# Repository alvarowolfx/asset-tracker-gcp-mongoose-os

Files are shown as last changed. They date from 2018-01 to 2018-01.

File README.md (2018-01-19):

# Asset Tracker using MongooseOS and Google Cloud

## Overview

IoT Project using MongooseOS with it's awesome GPRS with PPPoS. Data will be sent to Google Cloud to be analysed and visualized.

WebApp: https://asset-tracker-iot.firebaseapp.com

### Upload firmware with Mongoose OS Tools

To use it we need to download and install it from the official website. Follow the installation instructions on https://mongoose-os.com/docs/quickstart/setup.html.

* `mos build --arch esp32`
* `mos flash`

### Provision and config

* `mos wifi your_ssid your_pass`
* `mos gcp-iot-setup --gcp-project your_project --gcp-region us-central1 --gcp-registry your_registry`

### BOM

* Any ESP32 Board (I used a Lolin32).
* NEO 6M uBlox GPS module.
* Sim800L GSM module.
* 220 Ohm resistor for the LED.
* Blue and Green LED for status of the device.
* 1k Ohm resistor for the MOSFET trigger.
* IRF540N MOSFET (don’t try to use a cheap MOSFET, like the TIP120, because it cannot handle the GSM Module current needs)
* Jumpers
* Perfboard for prototype (Optional)

### Schematic

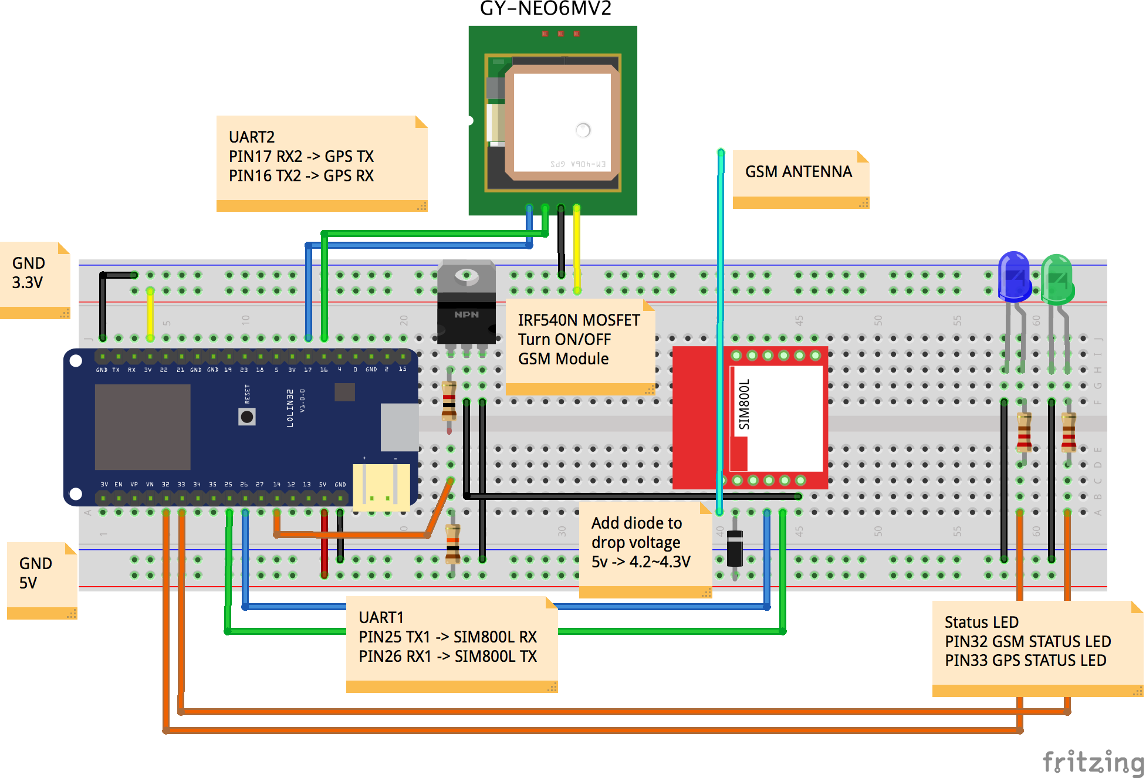
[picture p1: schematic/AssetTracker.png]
schematic


### Setup Firebase, deploy functions and webapp

* Install firebase tools: `npm install -g firebase-tools` or `yarn global add firebase-tools`
* Install webapp dependencies: `npm install` or `yarn install`
* Build React Application: `yarn run build` or `yarn run build`
* Install functions dependencies: `cd functions && npm install` or `cd functions && yarn install`
* Associate project with Firebase: `firebase init`
* Deploy all the things: `firebase deploy`

## References

* https://github.com/mongoose-os-apps/example-rpc-c
* https://github.com/mongoose-os-libs/pppos
* GPS NMEA Tracker - https://github.com/kosma/minmea

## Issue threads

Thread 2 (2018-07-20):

Watchdog  got triggered

vishnu-chalil, 2018-07-20:
I really dont understand what is the problem but when I run after falshing the code I get this error
Somebody please Help

[Jul 20 13:22:28.841] Task watchdog got triggered. The following tasks did not reset the watchdog in time:
[Jul 20 13:22:28.849]  - IDLE (CPU 0), backtrace: 0x400d13f4 0x40085f77
[Jul 20 13:22:28.854]
[Jul 20 13:22:28.854] Tasks currently running:
[Jul 20 13:22:28.856] CPU 0: mgos
[Jul 20 13:22:28.857] Aborting.
[Jul 20 13:22:28.858] abort() was called at PC 0x400d0f54 on core 0
[Jul 20 13:22:28.862]
[Jul 20 13:22:28.862] Backtrace: 0x4008775f 0x4008785f 0x400d0f54 0x40081cba 0x40129d73
[Jul 20 13:22:28.868] --- BEGIN CORE DUMP ---
[Jul 20 13:22:28.869] mos: catching core dump

vishnu-chalil, 2018-07-20:
And also can someone please tell what this means

[Jul 20 13:33:27.650] mgos_http_server_ini HTTP server started on [80]
[Jul 20 13:33:27.656] mgos_pppos_create    PPPoS UART1, 115200, fc off, APN 'www'
[Jul 20 13:33:27.664] mg_rpc_channel_uart  0x3ffd1000 UART0

alvarowolfx, 2018-07-23:
Can you show your APN config and what cellular network provider are you using ?

vishnu-chalil, 2018-08-02:
config_schema:
  - ["app", "o", {title: "App config"}]
  - ["app.update_interval", "i", 300, {title: "Update interval in seconds"}]
  - ["pppos.enable", true]
  - ["pppos.uart_no", 1]
  - ["pppos.baud_rate", 115200]
  - ["pppos.apn", "airtelgprs.com"]
  - ["pppos.user", ""]
  - ["pppos.pass", ""]
  - ["pppos.connect_cmd", "ATD*99***1#"]
  - ["gps.uart_no", 2]
  - ["gps.baud_rate", 9600]
  - ["gps.update_interval", 2000]
  - ["wifi.sta.enable", false]

Cellular network provider is airtel

vishnu-chalil, 2018-08-03:
I found the mistake.It was an error with incorrect pin connection

Closed 2018-08-03.

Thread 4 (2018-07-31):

MQTT SSL error

hexfusion, 2018-07-31:
GCP is very sensitive to time sync issues which can result in MQTT SSL errors.

ref: https://github.com/mongoose-os-libs/gcp/issues/1

vishnu-chalil, 2018-08-06:
I updated and build the firmware with new version tools and now I am stuck in this.All I get is this output

	[Aug  3 21:48:10.173] Setting timer with  300  seconds interval
	[Aug  3 21:48:10.188]   at init.js:181
	[Aug  3 21:48:10.190] MJS error: calling non-callable
	[Aug  3 21:48:10.193] mgos_pppos_uart_disp Connecting (UART2, APN 'airtelgprs.com')...
	[Aug  3 21:48:10.201] mongoose_poll        New heap free LWM: 188456
	[Aug  3 21:48:10.206] mgos_net_on_change_c PPP: disconnected
	[Aug  3 21:48:12.690] mgos_net_on_change_c PPP: connecting
	[Aug  3 21:48:12.825] mgos_net_on_change_c PPP: connected
	[Aug  3 21:48:12.829] mgos_pppos_uart_disp Starting PPP, user ''
	[Aug  3 21:48:12.848] mongoose_poll        New heap free LWM: 186520
	[Aug  3 21:48:18.880] mgos_pppos_status_cb Error 6 (phase 0), reconnect
	[Aug  3 21:48:18.886] mgos_pppos_uart_disp Connecting (UART2, APN 'airtelgprs.com')...
	```
	[Aug  3 21:48:18.893] mgos_net_on_change_c PPP: disconnected
	[Aug  3 21:48:21.281] mgos_net_on_change_c PPP: connecting
	[Aug  3 21:48:21.796] mgos_net_on_change_c PPP: connected
	[Aug  3 21:48:21.801] mgos_pppos_uart_disp Starting PPP, user ''
	[Aug  3 21:48:21.820] mongoose_poll        New heap free LWM: 185688
	[Aug  3 21:48:27.851] mgos_pppos_status_cb Error 6 (phase 0), reconnect
	[Aug  3 21:48:27.857] mgos_pppos_uart_disp Connecting (UART2, APN 'airtelgprs.com')...

Is there something that I could have possibly missed

Closed 2018-07-31.

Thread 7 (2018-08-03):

MJS error: calling non-callable

vishnu-chalil, 2018-08-03:
I updated and builded the firmware with new version tools and now Iam stuck in this.All I get is this output

[Aug  3 21:48:10.173] Setting timer with  300  seconds interval
[Aug  3 21:48:10.188]   at init.js:181
[Aug  3 21:48:10.190] MJS error: calling non-callable
[Aug  3 21:48:10.193] mgos_pppos_uart_disp Connecting (UART2, APN 'airtelgprs.com')...
[Aug  3 21:48:10.201] mongoose_poll        New heap free LWM: 188456
[Aug  3 21:48:10.206] mgos_net_on_change_c PPP: disconnected
[Aug  3 21:48:12.690] mgos_net_on_change_c PPP: connecting
[Aug  3 21:48:12.825] mgos_net_on_change_c PPP: connected
[Aug  3 21:48:12.829] mgos_pppos_uart_disp Starting PPP, user ''
[Aug  3 21:48:12.848] mongoose_poll        New heap free LWM: 186520
[Aug  3 21:48:18.880] mgos_pppos_status_cb Error 6 (phase 0), reconnect
[Aug  3 21:48:18.886] mgos_pppos_uart_disp Connecting (UART2, APN 'airtelgprs.com')...
[Aug  3 21:48:18.893] mgos_net_on_change_c PPP: disconnected
[Aug  3 21:48:21.281] mgos_net_on_change_c PPP: connecting
[Aug  3 21:48:21.796] mgos_net_on_change_c PPP: connected
[Aug  3 21:48:21.801] mgos_pppos_uart_disp Starting PPP, user ''
[Aug  3 21:48:21.820] mongoose_poll        New heap free LWM: 185688
[Aug  3 21:48:27.851] mgos_pppos_status_cb Error 6 (phase 0), reconnect
[Aug  3 21:48:27.857] mgos_pppos_uart_disp Connecting (UART2, APN 'airtelgprs.com')...

bblanke, 2020-02-19:
Howdy! You might need to add the function to your object in Object.create.

Example from my code from another project:

`let ThermalPrinter = {
  create: function(uart_no, dtr_pin, heatTime) {
    return Object.create({
      _i: ThermalPrinter._c(uart_no, dtr_pin, heatTime),

      print: ThermalPrinter.print,
      had to add this >> println: ThermalPrinter.println
    });
  },

  print: function(str) {
    ThermalPrinter._print(this._i, str, str.length);
  },

  println: function(str) {
    ThermalPrinter._println(this._i, str, str.length);
  },

  _c: ffi('void *thermal_printer_create(int, int, int)'),
  _print: ffi('void print(void *, char *, int)'),
  _println: ffi('void println(void *, char *, int)'),
}`

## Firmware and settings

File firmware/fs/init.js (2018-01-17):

load('api_config.js');
load('api_uart.js');
load('api_gpio.js');
load('api_net.js');
load('api_mqtt.js');
load('api_sys.js');
load('api_timer.js');
load('api_esp32.js');
load('api_gps.js');

let isConnected = false;
let isGPSLocked = false;
let telemetrySend = false;
let deviceName = Cfg.get('device.id');
let topic = '/devices/' + deviceName + '/events';
//let stateTopic = '/devices/' + deviceName + '/state';
let configTopic = '/devices/' + deviceName + '/config';

let gpsStatusPin = 33;
let gsmStatusPin = 32;
let gsmSwitchPin = 14;

GPIO.set_mode(gpsStatusPin, GPIO.MODE_OUTPUT);
GPIO.set_mode(gsmStatusPin, GPIO.MODE_OUTPUT);
GPIO.set_mode(gsmSwitchPin, GPIO.MODE_OUTPUT);

GPIO.write(gpsStatusPin, 0); // Turn off gps led
GPIO.write(gsmStatusPin, 0); // Turn off gsm led
GPIO.write(gsmSwitchPin, 1); // Turn on gsm module

function getTemp() {
  return (ESP32.temp() - 32) * 5 / 9;
}

function getParsedLatLon() {
  return GPS.getLocation();
}

let getInfo = function() {
  return JSON.stringify({
    total_ram: Sys.total_ram() / 1024,
    free_ram: Sys.free_ram() / 1024,
    temp: getTemp(),
    latlon: getParsedLatLon()
  });
};

function publishData() {
  let msg = getInfo();
  let ok = MQTT.pub(topic, msg);
  if (ok) {
    print('Published');
  } else {
    print('Error publishing');
  }
  return ok;
}

// Sleep function, turning off all LEDs and GSM modem.
let updateTimerId = null;
let gpsTimerId = null;
function goToSleep() {
  print('Sleeping');
  Timer.del(gpsTimerId);
  Timer.del(updateTimerId);
  Timer.set(
    8000,
    false,
    function() {
      GPIO.write(gpsStatusPin, 0); // Turn off gps led
      GPIO.write(gsmStatusPin, 0); // Turn off gsm led
      GPIO.write(gsmSwitchPin, 0); // Turn off gsm module

      let updateInterval = Cfg.get('app.update_interval');

      ESP32.deepSleep(updateInterval * 1000 * 1000);
    },
    null
  );
}

// Setup a timer that keep track of the time that the device is on but didn't send data yet.
// After some tries it goes to sleep.
let sendTelemetryTries = 0;
function setUpdateTimer() {
  if (updateTimerId) {
    Timer.del(updateTimerId);
  }
  let updateInterval = Cfg.get('app.update_interval');
  print('Setting timer with ', updateInterval, ' seconds interval');
  updateTimerId = Timer.set(
    updateInterval * 1000,
    true,
    function() {
      print('Should send telemetry');
      sendTelemetryTries = sendTelemetryTries + 1;
      if (sendTelemetryTries > 1 && !telemetrySend) {
        goToSleep();
      }
      telemetrySend = false;
    },
    null
  );
}
setUpdateTimer();

// Check if GPS has valid data.
gpsTimerId = Timer.set(
  1000,
  true,
  function() {
    let geo = getParsedLatLon();
    if (geo) {
      isGPSLocked = true;
      GPIO.write(gpsStatusPin, 1);
    } else {
      isGPSLocked = false;
      GPIO.write(gpsStatusPin, 0);
    }
  },
  null
);

// Checks if is connected to mqtt server and GPS is locked
// Then send data thought mqtt and if it's all ok, go to sleep
Timer.set(
  5000,
  true,
  function() {
    if (isConnected && isGPSLocked && !telemetrySend) {
      let ok = publishData();
      telemetrySend = ok;

      if (telemetrySend) {
        goToSleep();
      }
    }
  },
  null
);

// Subscribe to Cloud IoT Core configuration topic
MQTT.sub(
  configTopic,
  function(conn, topic, msg) {
    print('Got config update:', msg.slice(0, 100));
    if (!msg) {
      return;
    }
    let obj = JSON.parse(msg);
    if (obj) {
      Cfg.set({ app: obj });
    }
    setUpdateTimer();
  },
  null
);

// Monitor connection with MQTT server
MQTT.setEventHandler(function(conn, ev) {
  if (ev === MQTT.EV_CONNACK) {
    print('MQTT CONNECTED');
    isConnected = true;
    GPIO.write(gsmStatusPin, 1);
  }
}, null);

// Monitor network connectivity.
Net.setStatusEventHandler(function(ev, arg) {
  let evs = '???';
  if (ev === Net.STATUS_DISCONNECTED) {
    evs = 'DISCONNECTED';
    isConnected = false;
    GPIO.write(gsmStatusPin, 0);
  } else if (ev === Net.STATUS_CONNECTING) {
    evs = 'CONNECTING';
  } else if (ev === Net.STATUS_CONNECTED) {
    evs = 'CONNECTED';
  } else if (ev === Net.STATUS_GOT_IP) {
    evs = 'GOT_IP';
  }
  print('== Net event:', ev, evs);
}, null);

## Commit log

2017-11-23 [feat] GPS and GPRS status led
2017-12-17 [chore] Move device code to firmware folder
2017-12-21 [feat] Add turn off switch for GSM modem and use deep sleep
2017-12-24 [fix] Rollback mos version, hal interrup problem on 1.22
    [init.js]
2017-12-28 [feat] Change device config API
2017-12-31 [feat] Manage device date index
2017-12-31 [feat] Locations filters and device config
2018-01-12 [chore] Better docs with schematic
    [AssetTracker.fzz]
2018-01-12 [chore] Straight jumpers :lipstick:
    [AssetTracker.fzz]
2018-01-17 [feat] Better docs
    [AssetTracker.fzz]
